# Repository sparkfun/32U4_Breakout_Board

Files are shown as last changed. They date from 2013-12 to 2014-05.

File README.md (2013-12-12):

ATMEGA32U4 Breakout Board
=========================

[ATMEGA32U4 Breakout 
*ATMEGA32U4 Breakout Board (DEV-11117)*](https://www.sparkfun.com/products/11117)

This breakout board is designed for folks who would like to program outside of the Arduino IDE. THe board
comes preloaded with the LUFA CDC bootloader, allowing code to be built in WinAVR and program the board over USB
using AVRDUDE. 

Repository Contents
-------------------
* **/Bootloaders** - CDC bootloader and instructions for installation
* **/Examples** - Example code for the board
* **/Hardware** - All Eagle design files (.brd, .sch)
* **/LUFA** - Instructions for setting up the LUFA bootloader

License Information
-------------------
The hardware is released under [Creative Commons Share-alike 3.0](http://creativecommons.org/licenses/by-sa/3.0/).  
All other code is open source so please feel free to do anything you want with it; you buy me a beer if you use this and we meet someday ([Beerware license](http://en.wikipedia.org/wiki/Beerware)).

Notes for Installation
----------------------
This directory contains the bootloader and example source files for
Sparkfun's 32u4 Breakout board. Both were built on WinXP sp3 with
WinAVR-20100110 and AVRDUDE 5.10.

The bootloader is a modified LUFA-130303 CDC bootloader.

The bootloader directory contains the source and hex file for the bootloader
that ships with this board.  When you first plug in the board to a Windows
machine, it will ask you for a driver.  Point it to the following directory:
\SFE_32U4_Breakout_Board\Bootloaders\CDC
It will find the driver file (LUFA CDC Bootloader.inf) there.

Once your machine recognizes the Virtual COM port, you're ready to take a
look at the examples and try uploading them to your board. See the readme in
the examples directory for more information.

Before you can build any projects, you'll need to download and install
WinAVR if you're using Windows. It can be found [here](http://sourceforge.net/projects/winavr/files/). 

Linux Users
-----------
You will need to install the following packages:
* **avr-gcc** - A port of the GNU C compiler to the AVR Architecture
* **avr-binutils** - Converts the object code into AVR-readable hex files
* **avr-libc** - AVR Library for stuff like accessing and manipulating registers
* **avrdude** - The software that actually drives the physical programming

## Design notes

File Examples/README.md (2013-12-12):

This directory contains various examples for the SparkFun 32u4 Breakout Board.
==============================================================================

All examples can be built using the command line.
Each example includes the appropriate source files and a hex file for quick testing.

To build:
----------
CD (change directory) into the appropriate folder such as:
\SFE_32U4_Breakout_Board\Examples\32U4_digital_output

Type the command 'make' or 'make all' and hit enter.
This builds the project and gives you a .hex file for the microcontroller.
Other build files are also created.

To clean:
---------
To get rid of all build files, use the command 'make clean'.

To program:
-----------
You can download a program a hex file to your Sparkfun 32u4 Breakout Board by first
hitting the physical reset button on the device.  This will put the device into
its bootloader state.  Then use the command 'make program'.

Examples:
---------
1. 32U4 digital output

Important files: main.c, makefile, main.hex

Demonstrates how to output a state, HIGH or LOW, to a pin.

2. 32U4 digital input

Important files: main.c, makefile, main.hex

Demonstrates to to read the input state of a pin, HIGH or LOW.

3. Sparkfun-VirtualSerial

Important files: VirtualSerial.c, makefile, VirtualSerial-ex1.hex, VirtualSerial-ex2.hex

Demonstrates basic functionality of how to send and receive characters from a PC via
USB and a virtual COM port.  Includes two examples.  VirtualSerial.c contains both
examples however, example 1 is active and 2 is commented out by default.  To try 
example 2, uncomment it and comment example 1.  The file has more detail.  If you
want to try either example without building the project, just download the
appropriate hex file to your board.

Notes concerning programming the board:
---------------------------------------

You will almost certainly have to change the line in the Makefile which specifies
which COM port to talk to. The line looks like this:
AVRDUDE_PORT = COM19
Change 'COM19' to 'COMx' where x is the number of the Sparkfun COM port that shows
up when you connect your 32u4 Breakout to the PC. This is an instruction for Windows,
however you do the same for MAC/Linux only they have fairly different COM port names.
Also, Windows asks for a driver the first time you plug in your board, direct it 
to the .inf file located in the \SFE_32U4_Breakout_Board\Bootloaders\CDC directory 
the first time you plug your board in.

Now that the board is programmed with an application the board will start in the 
user application when turned on.  If you want to reprogram a user application, 
you'll want to run the bootloader again.  To do this just hit the manual reset button
on the board.  Whenever the reset button is pressed, the bootloader runs.  So for 
programming in the future, just hit reset, type make program and hit enter.  
The programming will fail if the board isn't in its bootloader state.

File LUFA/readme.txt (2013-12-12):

                   _   _ _ ___ _
                  | | | | | __/ \
                  | |_| U | _| o | - The Lightweight USB
                  |___|___|_||_n_|    Framework for AVRs
                =========================================
                          Written by Dean Camera
                  dean [at] fourwalledcubicle [dot] com

                         http://www.lufa-lib.org
                =========================================

               LUFA is donation supported. To support LUFA,
             please donate at http://www.lufa-lib.org/donate

                For Commercial Licensing information, see
                     http://www.lufa-lib.org/license

Notes from SparkFun:

In order to compile the modified LUFA bootloader, or the Virtual Serial
example for your Sparkfun 32u4 Breakout Board, follow these instructions:

1. Download the LUFA Project, version 130303,  version 120219 for VirtualSerial

Visit http://www.lufa-lib.org, then download LUFA-130303.zip

Alternatively, use the following official link to the file:
lufa-lib.googlecode.com/files/LUFA-130303.zip

2. Extract the zip file somewhere on your computer.

3. Copy the contents of the 'LUFA' folder from the zip to this folder.

The folder should be in the main directory:
\LUFA-130303\LUFA

Copy everything in that folder to this one where this readme resides:
\SFE_32U4_Breakout_Board\LUFA

4. ???

5. Profit!

You can now compile the Sparkfun modified LUFA bootloader and the Virtual
Serial demo found in the following locations respectively:
\SFE_32U4_Breakout_Board\Bootloaders\CDC
\SFE_32U4_Breakout_Board\Examples\Sparkfun-VirtualSerial

Enjoy!!

Also, a note about other examples included with the LUFA download:

LUFA includes all sorts of other examples too but they need their makefiles 
to be customized to work for the 32u4 processor and their driver files 
(.inf files and Descriptors.c) to be customized for Sparkfun's 32u4 Breakout
Board. More specifically, you will have to change the VID and PID in those 
files for them to work with this specific board, so just a heads up.

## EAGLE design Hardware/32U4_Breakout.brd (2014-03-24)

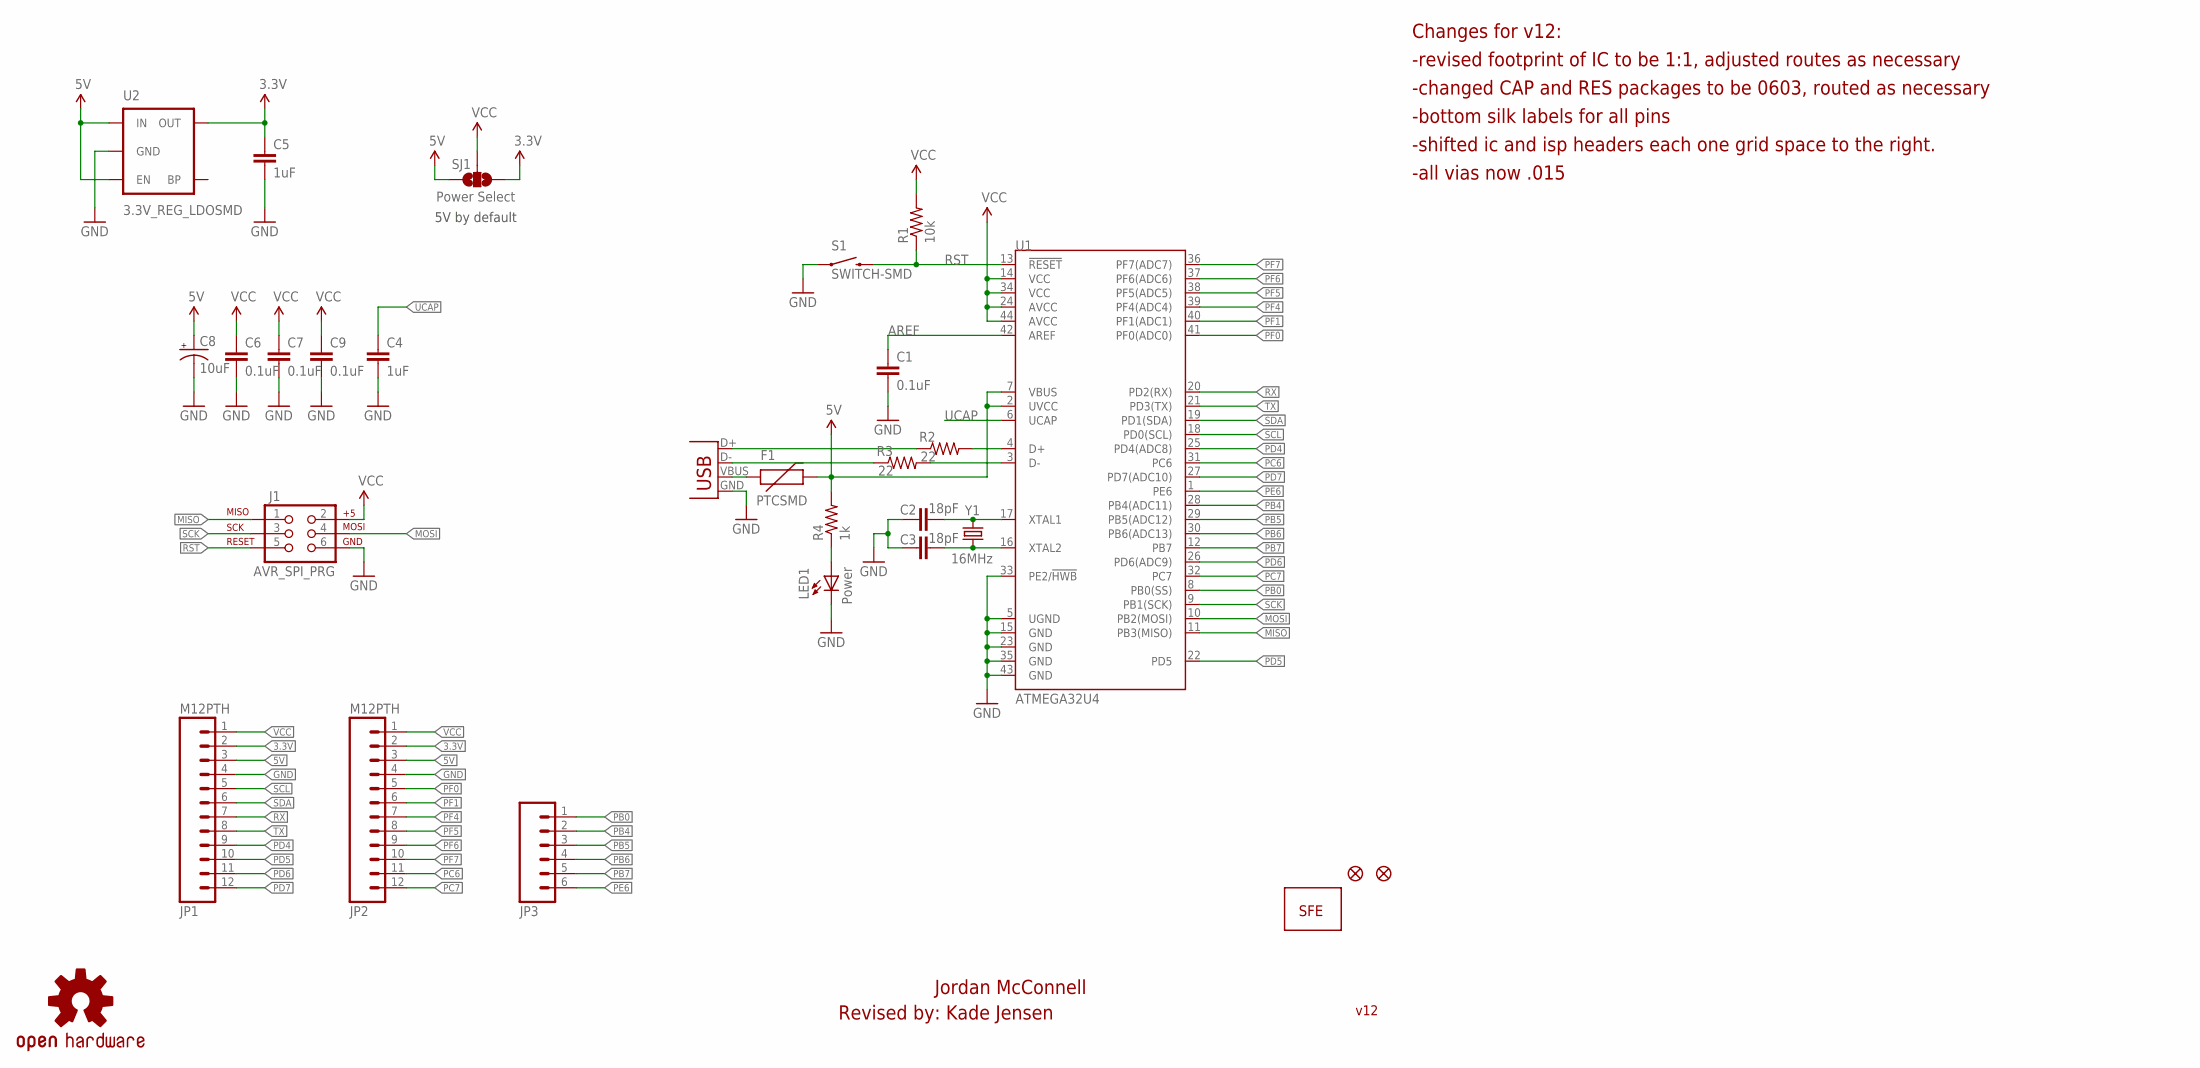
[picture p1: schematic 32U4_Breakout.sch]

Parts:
C1, C6, C7, C9: 0.1uF; 0603-CAP
C2, C3: 18pF; 0603-CAP
C4, C5: 1uF; 0603-CAP
C8: 10uF; EIA3216
F1: PTCSMD; PTC-1206
J1: AVR_SPI_PRG; 2X3
JP1, JP2: M12PTH; 1X12
JP3: M06SIP; 1X06
JP6, JP7: FIDUCIAL1X2; FIDUCIAL-1X2
JP8: LOGO-SFENEW; SFE-NEW-WEBLOGO
LED1: Power; LED-0603
R1: 10k; 0603-RES
R2, R3: 22; 0603-RES
R4: 1k; 0603-RES
S1: SWITCH-SMD; TACTILE_SWITCH_SMD
SJ1: Power Select; SJ_3_PASTE2&3
U1: ATMEGA32U4; QFN-44-NOPAD_1:1
U2: 3.3V_REG_LDOSMD; SOT23-5
U$6: OSHW-LOGOM; OSHW-LOGO-M
X1: USBSMD; USB-MINIB
Y1: 16MHz; CRYSTAL-SMD-5X3

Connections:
3.3V: C5.1, JP1.2, JP2.2, SJ1.1, U2.5 (OUT)
5V: C8.A (+), F1.2, JP1.3, JP2.3, R4.2, SJ1.3, U1.2 (UVCC), U1.7 (VBUS), U2.1 (IN), U2.3 (EN)
AREF: C1.1, U1.42 (AREF)
D+: R2.1, X1.D+
D-: R3.1, X1.D-
GND: C1.2, C2.1, C3.1, C4.2, C5.2, C6.2, C7.2, C8.C (-), C9.2, J1.6, JP1.4, JP2.4, LED1.C, S1.1, U1.5 (UGND), U1.15 (GND), U1.23 (GND), U1.33 (PE2/!HWB), U1.35 (GND), U1.43 (GND), U2.2 (GND), X1.GND
MISO: J1.1, U1.11 (PB3(MISO))
MOSI: J1.4, U1.10 (PB2(MOSI))
unnamed: C2.2, U1.17 (XTAL1), Y1.3 (2)
unnamed: C3.2, U1.16 (XTAL2), Y1.1
unnamed: F1.1, X1.VBUS
unnamed: R2.2, U1.4 (D+)
unnamed: R3.2, U1.3 (D-)
unnamed: LED1.A, R4.1
PB0: JP3.1, U1.8 (PB0(SS))
PB4: JP3.2, U1.28 (PB4(ADC11))
PB5: JP3.3, U1.29 (PB5(ADC12))
PB6: JP3.4, U1.30 (PB6(ADC13))
PB7: JP3.5, U1.12 (PB7)
PC6: JP2.11, U1.31 (PC6)
PC7: JP2.12, U1.32 (PC7)
PD4: JP1.9, U1.25 (PD4(ADC8))
PD5: JP1.10, U1.22 (PD5)
PD6: JP1.11, U1.26 (PD6(ADC9))
PD7: JP1.12, U1.27 (PD7(ADC10))
PE6: JP3.6, U1.1 (PE6)
PF0: JP2.5, U1.41 (PF0(ADC0))
PF1: JP2.6, U1.40 (PF1(ADC1))
PF4: JP2.7, U1.39 (PF4(ADC4))
PF5: JP2.8, U1.38 (PF5(ADC5))
PF6: JP2.9, U1.37 (PF6(ADC6))
PF7: JP2.10, U1.36 (PF7(ADC7))
RST: J1.5, R1.1, S1.3 (2), U1.13 (!RESET)
RX: JP1.7, U1.20 (PD2(RX))
SCK: J1.3, U1.9 (PB1(SCK))
SCL: JP1.5, U1.18 (PD0(SCL))
SDA: JP1.6, U1.19 (PD1(SDA))
TX: JP1.8, U1.21 (PD3(TX))
UCAP: C4.1, U1.6 (UCAP)
VCC: C6.1, C7.1, C9.1, J1.2, JP1.1, JP2.1, R1.2, SJ1.2, U1.14 (VCC), U1.24 (AVCC), U1.34 (VCC), U1.44 (AVCC)

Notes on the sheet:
Changes for v12:
-revised footprint of IC to be 1:1, adjusted routes as necessary
-changed CAP and RES packages to be 0603, routed as necessary
-bottom silk labels for all pins
-shifted ic and isp headers each one grid space to the right.
Jordan McConnell
Revised by: Kade Jensen
-all vias now .015
5V by default
v12

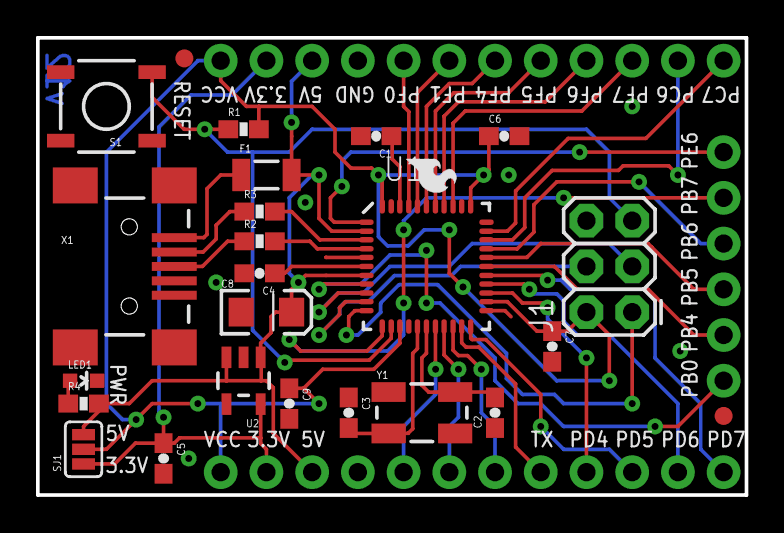
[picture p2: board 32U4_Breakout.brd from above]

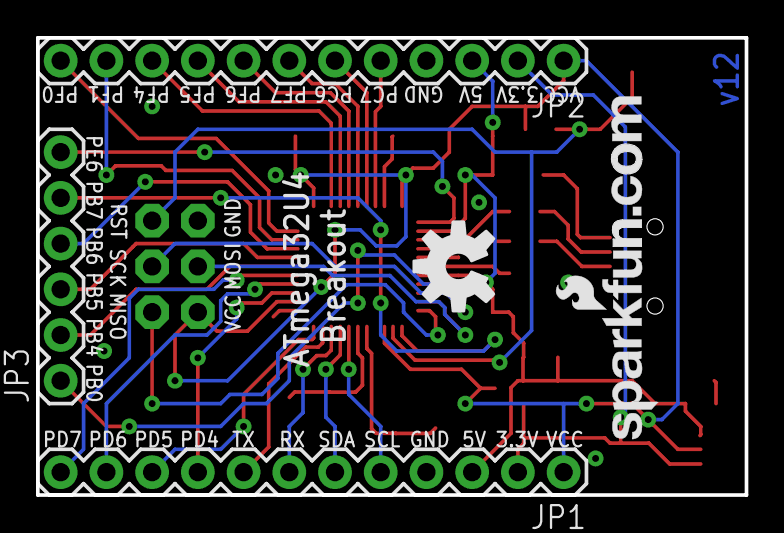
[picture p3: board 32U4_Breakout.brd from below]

Board: 2 copper layers, 39.4 x 25.4 mm, 30 parts (5 on the bottom side), 40 nets.

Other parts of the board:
JP5: LOGO-SFESK; SFE-LOGO-FLAME

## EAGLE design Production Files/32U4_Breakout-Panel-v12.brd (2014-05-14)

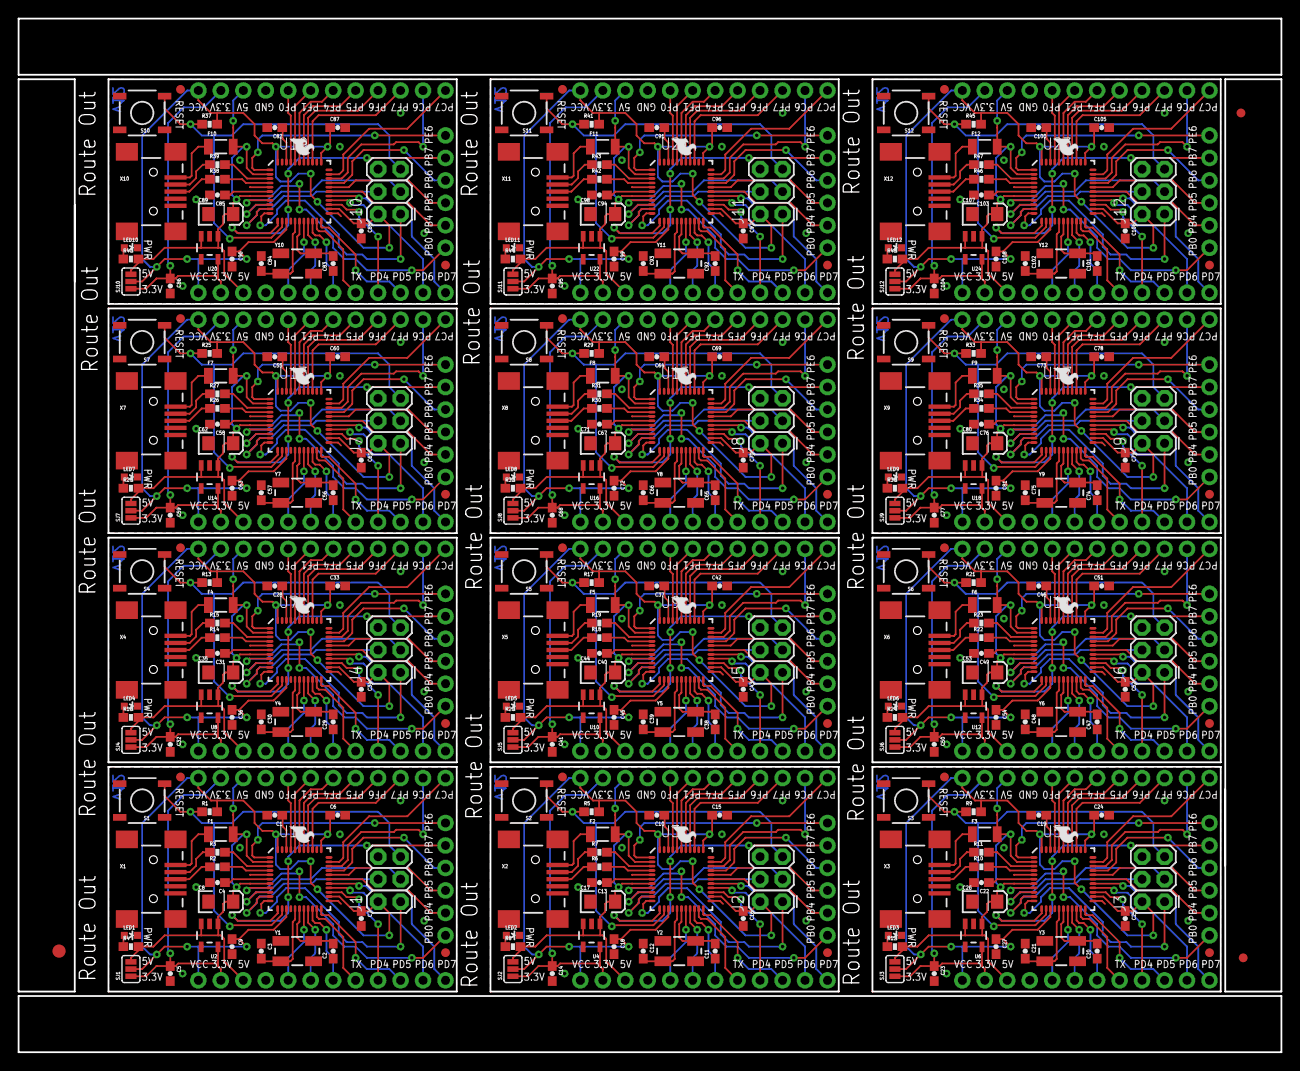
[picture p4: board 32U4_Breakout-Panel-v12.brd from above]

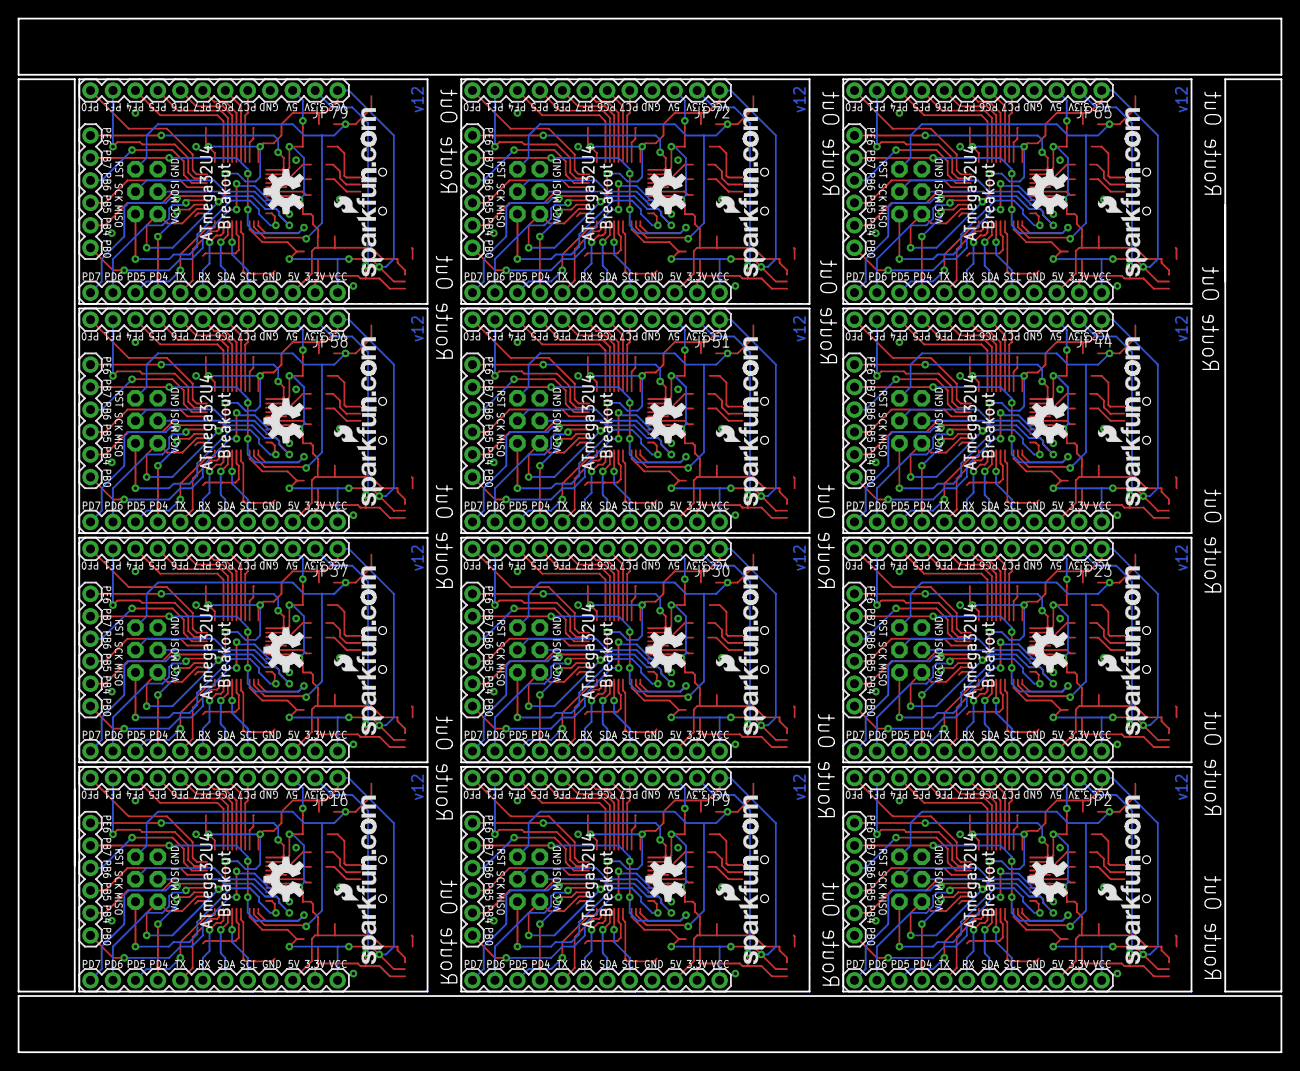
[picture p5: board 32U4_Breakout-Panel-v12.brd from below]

Board: 2 copper layers, 142.7 x 116.8 mm, 363 parts (60 on the bottom side), 480 nets.

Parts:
C1, C6, C7, C9, C10, C15, C16, C18, C19, C24, C25, C27, C28, C33, C34, C36, C37, C42, C43, C45, C46, C51, C52, C54, C55, C60, C61, C63, C64, C69, C70, C72, C73, C78, C79, C81, C82, C87, C88, C90, C91, C96, C97, C99, C100, C105, C106, C108: 0.1uF; 0603-CAP
C2, C3, C11, C12, C20, C21, C29, C30, C38, C39, C47, C48, C56, C57, C65, C66, C74, C75, C83, C84, C92, C93, C101, C102: 18pF; 0603-CAP
C4, C5, C13, C14, C22, C23, C31, C32, C40, C41, C49, C50, C58, C59, C67, C68, C76, C77, C85, C86, C94, C95, C103, C104: 1uF; 0603-CAP
C8, C17, C26, C35, C44, C53, C62, C71, C80, C89, C98, C107: 10uF; EIA3216
E$1: FIDUCIAL-1.5X3
E$4, E$5: FIDUCIAL-1X2
F1, F2, F3, F4, F5, F6, F7, F8, F9, F10, F11, F12: PTCSMD; PTC-1206
J1, J2, J3, J4, J5, J6, J7, J8, J9, J10, J11, J12: AVR_SPI_PRG; 2X3
JP1, JP2, JP4, JP9, JP15, JP16, JP22, JP23, JP29, JP30, JP36, JP37, JP43, JP44, JP50, JP51, JP57, JP58, JP64, JP65, JP71, JP72, JP78, JP79: M12PTH; 1X12
JP3, JP10, JP17, JP24, JP31, JP38, JP45, JP52, JP59, JP66, JP73, JP80: 1X06
JP5, JP11, JP18, JP25, JP32, JP39, JP46, JP53, JP60, JP67, JP74, JP81: LOGO-SFESK; SFE-LOGO-FLAME
JP6, JP7, JP12, JP13, JP19, JP20, JP26, JP27, JP33, JP34, JP40, JP41, JP47, JP48, JP54, JP55, JP61, JP62, JP68, JP69, JP75, JP76, JP82, JP83: FIDUCIAL1X2; FIDUCIAL-1X2
JP8, JP14, JP21, JP28, JP35, JP42, JP49, JP56, JP63, JP70, JP77, JP84: LOGO-SFENEW; SFE-NEW-WEBLOGO
LED1, LED2, LED3, LED4, LED5, LED6, LED7, LED8, LED9, LED10, LED11, LED12: Power; LED-0603
R1, R5, R9, R13, R17, R21, R25, R29, R33, R37, R41, R45: 10k; 0603-RES
R2, R3, R6, R7, R10, R11, R14, R15, R18, R19, R22, R23, R26, R27, R30, R31, R34, R35, R38, R39, R42, R43, R46, R47: 22; 0603-RES
R4, R8, R12, R16, R20, R24, R28, R32, R36, R40, R44, R48: 1k; 0603-RES
S1, S2, S3, S4, S5, S6, S7, S8, S9, S10, S11, S12: SWITCH-SMD; TACTILE_SWITCH_SMD
SJ1, SJ2, SJ3, SJ4, SJ5, SJ6, SJ7, SJ8, SJ9, SJ10, SJ11, SJ12: Power Select; SJ_3_PASTE2&3
U1, U3, U5, U7, U9, U11, U13, U15, U17, U19, U21, U23: ATMEGA32U4; QFN-44-NOPAD_1:1-LESS_PASTE
U2, U4, U6, U8, U10, U12, U14, U16, U18, U20, U22, U24: 3.3V_REG_LDOSMD; SOT23-5
U$1, U$2, U$3, U$4, U$5, U$6, U$7, U$8, U$9, U$10, U$11, U$12: OSHW-LOGOM; OSHW-LOGO-M
X1, X2, X3, X4, X5, X6, X7, X8, X9, X10, X11, X12: USBSMD; USB-MINIB
Y1, Y2, Y3, Y4, Y5, Y6, Y7, Y8, Y9, Y10, Y11, Y12: 16MHz; CRYSTAL-SMD-5X3

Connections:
3.3V: C5.1, JP1.2, JP2.2, SJ1.1, U2.5
3.3V1: C14.1, JP4.2, JP9.2, SJ2.1, U4.5
3.3V2: C23.1, JP15.2, JP16.2, SJ3.1, U6.5
3.3V3: C32.1, JP22.2, JP23.2, SJ4.1, U8.5
3.3V4: C41.1, JP29.2, JP30.2, SJ5.1, U10.5
3.3V5: C50.1, JP36.2, JP37.2, SJ6.1, U12.5
3.3V6: C59.1, JP43.2, JP44.2, SJ7.1, U14.5
3.3V7: C68.1, JP50.2, JP51.2, SJ8.1, U16.5
3.3V8: C77.1, JP57.2, JP58.2, SJ9.1, U18.5
3.3V9: C86.1, JP64.2, JP65.2, SJ10.1, U20.5
3.3V10: C95.1, JP71.2, JP72.2, SJ11.1, U22.5
3.3V11: C104.1, JP78.2, JP79.2, SJ12.1, U24.5
5V: C8.A, F1.2, JP1.3, JP2.3, R4.2, SJ1.3, U1.2, U1.7, U2.1, U2.3
5V1: C17.A, F2.2, JP4.3, JP9.3, R8.2, SJ2.3, U3.2, U3.7, U4.1, U4.3
5V2: C26.A, F3.2, JP15.3, JP16.3, R12.2, SJ3.3, U5.2, U5.7, U6.1, U6.3
5V3: C35.A, F4.2, JP22.3, JP23.3, R16.2, SJ4.3, U7.2, U7.7, U8.1, U8.3
5V4: C44.A, F5.2, JP29.3, JP30.3, R20.2, SJ5.3, U9.2, U9.7, U10.1, U10.3
5V5: C53.A, F6.2, JP36.3, JP37.3, R24.2, SJ6.3, U11.2, U11.7, U12.1, U12.3
5V6: C62.A, F7.2, JP43.3, JP44.3, R28.2, SJ7.3, U13.2, U13.7, U14.1, U14.3
5V7: C71.A, F8.2, JP50.3, JP51.3, R32.2, SJ8.3, U15.2, U15.7, U16.1, U16.3
5V8: C80.A, F9.2, JP57.3, JP58.3, R36.2, SJ9.3, U17.2, U17.7, U18.1, U18.3
5V9: C89.A, F10.2, JP64.3, JP65.3, R40.2, SJ10.3, U19.2, U19.7, U20.1, U20.3
5V10: C98.A, F11.2, JP71.3, JP72.3, R44.2, SJ11.3, U21.2, U21.7, U22.1, U22.3
5V11: C107.A, F12.2, JP78.3, JP79.3, R48.2, SJ12.3, U23.2, U23.7, U24.1, U24.3
AREF: C1.1, U1.42
AREF1: C10.1, U3.42
AREF2: C19.1, U5.42
AREF3: C28.1, U7.42
AREF4: C37.1, U9.42
AREF5: C46.1, U11.42
AREF6: C55.1, U13.42
AREF7: C64.1, U15.42
AREF8: C73.1, U17.42
AREF9: C82.1, U19.42
AREF10: C91.1, U21.42
AREF11: C100.1, U23.42
D+: R2.1, X1.D+
D+1: R6.1, X2.D+
D+2: R10.1, X3.D+
D+3: R14.1, X4.D+
D+4: R18.1, X5.D+
D+5: R22.1, X6.D+
D+6: R26.1, X7.D+
D+7: R30.1, X8.D+
D+8: R34.1, X9.D+
D+9: R38.1, X10.D+
D+10: R42.1, X11.D+
D+11: R46.1, X12.D+
D-: R3.1, X1.D-
D-1: R7.1, X2.D-
D-2: R11.1, X3.D-
D-3: R15.1, X4.D-
D-4: R19.1, X5.D-
D-5: R23.1, X6.D-
D-6: R27.1, X7.D-
D-7: R31.1, X8.D-
D-8: R35.1, X9.D-
D-9: R39.1, X10.D-
D-10: R43.1, X11.D-
D-11: R47.1, X12.D-
GND: C1.2, C2.1, C3.1, C4.2, C5.2, C6.2, C7.2, C8.C, C9.2, J1.6, JP1.4, JP2.4, LED1.C, S1.1, U1.5, U1.15, U1.23, U1.33, U1.35, U1.43, U2.2, X1.GND
GND1: C10.2, C11.1, C12.1, C13.2, C14.2, C15.2, C16.2, C17.C, C18.2, J2.6, JP4.4, JP9.4, LED2.C, S2.1, U3.5, U3.15, U3.23, U3.33, U3.35, U3.43, U4.2, X2.GND
GND2: C19.2, C20.1, C21.1, C22.2, C23.2, C24.2, C25.2, C26.C, C27.2, J3.6, JP15.4, JP16.4, LED3.C, S3.1, U5.5, U5.15, U5.23, U5.33, U5.35, U5.43, U6.2, X3.GND
GND3: C28.2, C29.1, C30.1, C31.2, C32.2, C33.2, C34.2, C35.C, C36.2, J4.6, JP22.4, JP23.4, LED4.C, S4.1, U7.5, U7.15, U7.23, U7.33, U7.35, U7.43, U8.2, X4.GND
GND4: C37.2, C38.1, C39.1, C40.2, C41.2, C42.2, C43.2, C44.C, C45.2, J5.6, JP29.4, JP30.4, LED5.C, S5.1, U9.5, U9.15, U9.23, U9.33, U9.35, U9.43, U10.2, X5.GND
GND5: C46.2, C47.1, C48.1, C49.2, C50.2, C51.2, C52.2, C53.C, C54.2, J6.6, JP36.4, JP37.4, LED6.C, S6.1, U11.5, U11.15, U11.23, U11.33, U11.35, U11.43, U12.2, X6.GND
GND6: C55.2, C56.1, C57.1, C58.2, C59.2, C60.2, C61.2, C62.C, C63.2, J7.6, JP43.4, JP44.4, LED7.C, S7.1, U13.5, U13.15, U13.23, U13.33, U13.35, U13.43, U14.2, X7.GND
GND7: C64.2, C65.1, C66.1, C67.2, C68.2, C69.2, C70.2, C71.C, C72.2, J8.6, JP50.4, JP51.4, LED8.C, S8.1, U15.5, U15.15, U15.23, U15.33, U15.35, U15.43, U16.2, X8.GND
GND8: C73.2, C74.1, C75.1, C76.2, C77.2, C78.2, C79.2, C80.C, C81.2, J9.6, JP57.4, JP58.4, LED9.C, S9.1, U17.5, U17.15, U17.23, U17.33, U17.35, U17.43, U18.2, X9.GND
GND9: C82.2, C83.1, C84.1, C85.2, C86.2, C87.2, C88.2, C89.C, C90.2, J10.6, JP64.4, JP65.4, LED10.C, S10.1, U19.5, U19.15, U19.23, U19.33, U19.35, U19.43, U20.2, X10.GND
GND10: C91.2, C92.1, C93.1, C94.2, C95.2, C96.2, C97.2, C98.C, C99.2, J11.6, JP71.4, JP72.4, LED11.C, S11.1, U21.5, U21.15, U21.23, U21.33, U21.35, U21.43, U22.2, X11.GND
GND11: C100.2, C101.1, C102.1, C103.2, C104.2, C105.2, C106.2, C107.C, C108.2, J12.6, JP78.4, JP79.4, LED12.C, S12.1, U23.5, U23.15, U23.23, U23.33, U23.35, U23.43, U24.2, X12.GND
MISO: J1.1, U1.11
MISO1: J2.1, U3.11
MISO2: J3.1, U5.11
MISO3: J4.1, U7.11
MISO4: J5.1, U9.11
MISO5: J6.1, U11.11
MISO6: J7.1, U13.11
MISO7: J8.1, U15.11
MISO8: J9.1, U17.11
MISO9: J10.1, U19.11
MISO10: J11.1, U21.11
MISO11: J12.1, U23.11
MOSI: J1.4, U1.10
MOSI1: J2.4, U3.10
MOSI2: J3.4, U5.10
MOSI3: J4.4, U7.10
MOSI4: J5.4, U9.10
MOSI5: J6.4, U11.10
MOSI6: J7.4, U13.10
MOSI7: J8.4, U15.10
MOSI8: J9.4, U17.10
MOSI9: J10.4, U19.10
MOSI10: J11.4, U21.10
MOSI11: J12.4, U23.10
unnamed: C11.2, U3.17, Y2.3
unnamed: C2.2, U1.17, Y1.3
unnamed: C3.2, U1.16, Y1.1
unnamed: F1.1, X1.VBUS
unnamed: C12.2, U3.16, Y2.1
unnamed: R2.2, U1.4
unnamed: R6.2, U3.4
unnamed: R3.2, U1.3
unnamed: LED1.A, R4.1
unnamed: R7.2, U3.3
unnamed: F2.1, X2.VBUS
unnamed: LED2.A, R8.1
unnamed: C20.2, U5.17, Y3.3
unnamed: C21.2, U5.16, Y3.1
unnamed: R10.2, U5.4
unnamed: R11.2, U5.3
unnamed: F3.1, X3.VBUS
unnamed: LED3.A, R12.1
unnamed: C29.2, U7.17, Y4.3
unnamed: C30.2, U7.16, Y4.1
unnamed: R14.2, U7.4
unnamed: R15.2, U7.3
unnamed: F4.1, X4.VBUS
unnamed: LED4.A, R16.1
unnamed: C38.2, U9.17, Y5.3
unnamed: C39.2, U9.16, Y5.1
unnamed: R18.2, U9.4
unnamed: R19.2, U9.3
unnamed: F5.1, X5.VBUS
unnamed: LED5.A, R20.1
unnamed: C47.2, U11.17, Y6.3
unnamed: C48.2, U11.16, Y6.1
unnamed: R22.2, U11.4
unnamed: R23.2, U11.3
unnamed: F6.1, X6.VBUS
unnamed: LED6.A, R24.1
unnamed: C56.2, U13.17, Y7.3
unnamed: C57.2, U13.16, Y7.1
unnamed: R26.2, U13.4
unnamed: R27.2, U13.3
unnamed: F7.1, X7.VBUS
unnamed: LED7.A, R28.1
unnamed: C65.2, U15.17, Y8.3
unnamed: C66.2, U15.16, Y8.1
unnamed: R30.2, U15.4
unnamed: R31.2, U15.3
unnamed: F8.1, X8.VBUS
unnamed: LED8.A, R32.1
unnamed: C74.2, U17.17, Y9.3
unnamed: C75.2, U17.16, Y9.1
unnamed: R34.2, U17.4
unnamed: R35.2, U17.3
unnamed: F9.1, X9.VBUS
unnamed: LED9.A, R36.1
unnamed: C83.2, U19.17, Y10.3
unnamed: C84.2, U19.16, Y10.1
unnamed: R38.2, U19.4
unnamed: R39.2, U19.3
unnamed: F10.1, X10.VBUS
unnamed: LED10.A, R40.1
unnamed: C92.2, U21.17, Y11.3
unnamed: C93.2, U21.16, Y11.1
unnamed: R42.2, U21.4
unnamed: R43.2, U21.3
unnamed: F11.1, X11.VBUS
unnamed: LED11.A, R44.1
unnamed: C101.2, U23.17, Y12.3
unnamed: C102.2, U23.16, Y12.1
unnamed: R46.2, U23.4
unnamed: R47.2, U23.3
unnamed: F12.1, X12.VBUS
unnamed: LED12.A, R48.1
PB0: JP3.1, U1.8
PB1: JP10.2, U3.28
PB2: JP10.3, U3.29
PB3: JP10.4, U3.30
PB4: JP3.2, U1.28
PB5: JP3.3, U1.29
PB6: JP3.4, U1.30
PB7: JP3.5, U1.12
PB8: JP10.5, U3.12
PB9: JP10.1, U3.8
PB10: JP17.2, U5.28
PB11: JP17.3, U5.29
PB12: JP17.4, U5.30
PB13: JP17.5, U5.12
PB14: JP17.1, U5.8
PB15: JP24.2, U7.28
PB16: JP24.3, U7.29
PB17: JP24.4, U7.30
PB18: JP24.5, U7.12
PB19: JP24.1, U7.8
PB20: JP31.2, U9.28
PB21: JP31.3, U9.29
PB22: JP31.4, U9.30
PB23: JP31.5, U9.12
PB24: JP31.1, U9.8
PB25: JP38.2, U11.28
PB26: JP38.3, U11.29
PB27: JP38.4, U11.30
PB28: JP38.5, U11.12
PB29: JP38.1, U11.8
PB30: JP45.2, U13.28
PB31: JP45.3, U13.29
PB32: JP45.4, U13.30
PB33: JP45.5, U13.12
PB34: JP45.1, U13.8
PB35: JP52.2, U15.28
PB36: JP52.3, U15.29
PB37: JP52.4, U15.30
PB38: JP52.5, U15.12
PB39: JP52.1, U15.8
PB40: JP59.2, U17.28
PB41: JP59.3, U17.29
PB42: JP59.4, U17.30
PB43: JP59.5, U17.12
PB44: JP59.1, U17.8
PB45: JP66.2, U19.28
PB46: JP66.3, U19.29
PB47: JP66.4, U19.30
PB48: JP66.5, U19.12
PB49: JP66.1, U19.8
PB50: JP73.2, U21.28
PB51: JP73.3, U21.29
PB52: JP73.4, U21.30
PB53: JP73.5, U21.12
PB54: JP73.1, U21.8
PB55: JP80.2, U23.28
PB56: JP80.3, U23.29
PB57: JP80.4, U23.30
PB58: JP80.5, U23.12
PB59: JP80.1, U23.8
PC1: JP9.11, U3.31
PC2: JP9.12, U3.32
PC3: JP16.11, U5.31
PC4: JP16.12, U5.32
PC5: JP23.11, U7.31
PC6: JP2.11, U1.31
PC7: JP2.12, U1.32
PC8: JP23.12, U7.32
PC9: JP30.11, U9.31
PC10: JP30.12, U9.32
PC11: JP37.11, U11.31
PC12: JP37.12, U11.32
PC13: JP44.11, U13.31
PC14: JP44.12, U13.32
PC15: JP51.11, U15.31
PC16: JP51.12, U15.32
PC17: JP58.11, U17.31
PC18: JP58.12, U17.32
PC19: JP65.11, U19.31
PC20: JP65.12, U19.32
PC21: JP72.11, U21.31
PC22: JP72.12, U21.32
PC23: JP79.11, U23.31
PC24: JP79.12, U23.32
PD1: JP4.9, U3.25
PD2: JP4.12, U3.27
PD3: JP4.11, U3.26
PD4: JP1.9, U1.25
PD5: JP1.10, U1.22
PD6: JP1.11, U1.26
PD7: JP1.12, U1.27
PD8: JP4.10, U3.22
PD9: JP15.9, U5.25
PD10: JP15.12, U5.27
PD11: JP15.11, U5.26
PD12: JP15.10, U5.22
PD13: JP22.9, U7.25
PD14: JP22.12, U7.27
PD15: JP22.11, U7.26
PD16: JP22.10, U7.22
PD17: JP29.9, U9.25
PD18: JP29.12, U9.27
PD19: JP29.11, U9.26
PD20: JP29.10, U9.22
PD21: JP36.9, U11.25
PD22: JP36.12, U11.27
PD23: JP36.11, U11.26
PD24: JP36.10, U11.22
PD25: JP43.9, U13.25
PD26: JP43.12, U13.27
PD27: JP43.11, U13.26
PD28: JP43.10, U13.22
PD29: JP50.9, U15.25
PD30: JP50.12, U15.27
PD31: JP50.11, U15.26
PD32: JP50.10, U15.22
PD33: JP57.9, U17.25
PD34: JP57.12, U17.27
PD35: JP57.11, U17.26
PD36: JP57.10, U17.22
PD37: JP64.9, U19.25
PD38: JP64.12, U19.27
PD39: JP64.11, U19.26
PD40: JP64.10, U19.22
PD41: JP71.9, U21.25
PD42: JP71.12, U21.27
PD43: JP71.11, U21.26
PD44: JP71.10, U21.22
PD45: JP78.9, U23.25
PD46: JP78.12, U23.27
PD47: JP78.11, U23.26
PD48: JP78.10, U23.22
PE1: JP10.6, U3.1
PE2: JP17.6, U5.1
PE3: JP24.6, U7.1
PE4: JP31.6, U9.1
PE5: JP38.6, U11.1
PE6: JP3.6, U1.1
PE7: JP45.6, U13.1
PE8: JP52.6, U15.1
PE9: JP59.6, U17.1
PE10: JP66.6, U19.1
PE11: JP73.6, U21.1
PE12: JP80.6, U23.1
PF0: JP2.5, U1.41
PF1: JP2.6, U1.40
PF2: JP9.10, U3.36
PF3: JP9.9, U3.37
PF4: JP2.7, U1.39
PF5: JP2.8, U1.38
PF6: JP2.9, U1.37
PF7: JP2.10, U1.36
PF8: JP9.8, U3.38
PF9: JP9.7, U3.39
PF10: JP9.6, U3.40
PF11: JP9.5, U3.41
PF12: JP16.10, U5.36
PF13: JP16.9, U5.37
PF14: JP16.8, U5.38
PF15: JP16.7, U5.39
PF16: JP16.6, U5.40
PF17: JP16.5, U5.41
PF18: JP23.10, U7.36
PF19: JP23.9, U7.37
PF20: JP23.8, U7.38
PF21: JP23.7, U7.39
PF22: JP23.6, U7.40
PF23: JP23.5, U7.41
PF24: JP30.10, U9.36
PF25: JP30.9, U9.37
PF26: JP30.8, U9.38
PF27: JP30.7, U9.39
PF28: JP30.6, U9.40
PF29: JP30.5, U9.41
PF30: JP37.10, U11.36
PF31: JP37.9, U11.37
PF32: JP37.8, U11.38
PF33: JP37.7, U11.39
PF34: JP37.6, U11.40
PF35: JP37.5, U11.41
PF36: JP44.10, U13.36
PF37: JP44.9, U13.37
PF38: JP44.8, U13.38
PF39: JP44.7, U13.39
PF40: JP44.6, U13.40
PF41: JP44.5, U13.41
PF42: JP51.10, U15.36
PF43: JP51.9, U15.37
PF44: JP51.8, U15.38
PF45: JP51.7, U15.39
PF46: JP51.6, U15.40
PF47: JP51.5, U15.41
PF48: JP58.10, U17.36
PF49: JP58.9, U17.37
PF50: JP58.8, U17.38
PF51: JP58.7, U17.39
PF52: JP58.6, U17.40
PF53: JP58.5, U17.41
PF54: JP65.10, U19.36
PF55: JP65.9, U19.37
PF56: JP65.8, U19.38
PF57: JP65.7, U19.39
PF58: JP65.6, U19.40
PF59: JP65.5, U19.41
PF60: JP72.10, U21.36
PF61: JP72.9, U21.37
PF62: JP72.8, U21.38
PF63: JP72.7, U21.39
PF64: JP72.6, U21.40
PF65: JP72.5, U21.41
PF66: JP79.10, U23.36
PF67: JP79.9, U23.37
PF68: JP79.8, U23.38
PF69: JP79.7, U23.39
PF70: JP79.6, U23.40
PF71: JP79.5, U23.41
RST: J1.5, R1.1, S1.3, U1.13
RST1: J2.5, R5.1, S2.3, U3.13
RST2: J3.5, R9.1, S3.3, U5.13
RST3: J4.5, R13.1, S4.3, U7.13
RST4: J5.5, R17.1, S5.3, U9.13
RST5: J6.5, R21.1, S6.3, U11.13
RST6: J7.5, R25.1, S7.3, U13.13
RST7: J8.5, R29.1, S8.3, U15.13
RST8: J9.5, R33.1, S9.3, U17.13
RST9: J10.5, R37.1, S10.3, U19.13
RST10: J11.5, R41.1, S11.3, U21.13
RST11: J12.5, R45.1, S12.3, U23.13
RX: JP1.7, U1.20
RX1: JP4.7, U3.20
RX2: JP15.7, U5.20
RX3: JP22.7, U7.20
RX4: JP29.7, U9.20
RX5: JP36.7, U11.20
RX6: JP43.7, U13.20
RX7: JP50.7, U15.20
RX8: JP57.7, U17.20
RX9: JP64.7, U19.20
RX10: JP71.7, U21.20
RX11: JP78.7, U23.20
SCK: J1.3, U1.9
SCK1: J2.3, U3.9
SCK2: J3.3, U5.9
SCK3: J4.3, U7.9
SCK4: J5.3, U9.9
SCK5: J6.3, U11.9
SCK6: J7.3, U13.9
SCK7: J8.3, U15.9
SCK8: J9.3, U17.9
SCK9: J10.3, U19.9
SCK10: J11.3, U21.9
SCK11: J12.3, U23.9
SCL: JP1.5, U1.18
SCL1: JP4.5, U3.18
SCL2: JP15.5, U5.18
SCL3: JP22.5, U7.18
SCL4: JP29.5, U9.18
SCL5: JP36.5, U11.18
SCL6: JP43.5, U13.18
SCL7: JP50.5, U15.18
SCL8: JP57.5, U17.18
SCL9: JP64.5, U19.18
SCL10: JP71.5, U21.18
SCL11: JP78.5, U23.18
SDA: JP1.6, U1.19
SDA1: JP4.6, U3.19
SDA2: JP15.6, U5.19
SDA3: JP22.6, U7.19
SDA4: JP29.6, U9.19
SDA5: JP36.6, U11.19
SDA6: JP43.6, U13.19
SDA7: JP50.6, U15.19
SDA8: JP57.6, U17.19
SDA9: JP64.6, U19.19
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

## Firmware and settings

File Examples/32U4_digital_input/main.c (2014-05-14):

/* Created 05/22/2012 by Jordan McConnell at Sparkfun Electronics
 * This code is beerware, you know what I'm sayin'?
 *
 * Built on WinXP SP3 and WinAVR-20100110, AVRDUDE 5.10
 *
 * This code is a simple example of digital input for Sparkfun's
 * 32U4 Breakout Board using C and standard AVR libraries.  It
 * teaches you how to read the status of a digital pin to determine
 * whether its current status is HIGH or LOW.
 *
 * Pin PF0 is used as a digital input.  If its status is HIGH,
 * pin PD5 toggles each second, if it's status is LOW, pin PD6
 * toggles each second instead.
 *
 * The user can connect LED's to pins PD5 and PD6 or use a multimeter
 * to verify operation.  If pin PF0 is left unconnected, it's status
 * will be HIGH due to internal pullup resistors, and PD5 toggles.
 * If PF0 is connected to ground, PD6 toggles each second instead.
 */

// Libraries for register names and the delay function
#include <avr/io.h>
#include <util/delay.h>

// Macros to make bit manipulation easier
#define set_bit(address,bit) (address |= (1<<bit))
#define clear_bit(address,bit) (address &= ~(1<<bit))
#define toggle_bit(address,bit) (address ^= (1<<bit))

// This macro is for checking if a certain bit is set in a given register.
// This is useful here for checking the status of individual input pins.
#define check_bit(address,bit) ((address & (1<<bit)) == (1<<bit))

int main(void)
{
    // The following line sets bit 5 HIGH in register DDRD
    set_bit(DDRD,5); // Pin PD5 is now configured as an OUTPUT
    set_bit(DDRD,6); // Pin PD6 is now configured as an OUTPUT

    // The following line sets bit 0 LOW in register DDRF
    clear_bit(DDRF,0); // Pin PF0 is now configured as an INPUT
    set_bit(PORTF,0); // Turn on internal pullups for PF0

    while(1)
    {
        // PINF is the register you have to read to check if a particular
        // pin on port F (PFx) is HIGH or LOW
        if(check_bit(PINF,0))
        {
            // If PF0 is HIGH, toggle pin PD5's output status
            toggle_bit(PORTD,5);
        }
        else
        {
            // If PF0 is LOW, toggle pin PD6's output status
            toggle_bit(PORTD,6);
        }

        _delay_ms(1000); // Delay 1 second before checking PF0 again

    }

    return 0;
}

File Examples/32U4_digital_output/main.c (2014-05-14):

/* Created 05/20/2012 by Jordan McConnell at Sparkfun Electronics
 * This code is beerware, you know what I'm sayin'?
 *
 * Built on WinXP SP3 and WinAVR-20100110, AVRDUDE 5.10
 *
 * This code is a simple example of digital output for Sparkfun's
 * 32U4 Breakout Board using C and standard AVR libraries.  It
 * teaches you how to set a pin high or low or toggle it from one
 * state to the other using pin PD5 as an example.
 *
 * The user can use a multimeter or LED on pin PD5 to verify that
 * the pin is indeed changing state between HIGH and LOW each second.
 */

// Libraries for register names (DDRD, PORTD) and the delay function
#include <avr/io.h>
#include <util/delay.h>

// Macros to make bit manipulation easier
// Macro tutorial found here: http://www.cprogramming.com/tutorial/cpreprocessor.html
// Bit manipulation tutorial found here: http://www.avrfreaks.net/index.php?name=PNphpBB2&file=viewtopic&t=37871
#define set_bit(address,bit) (address |= (1<<bit)) // sets BIT to 1 in the register specified with ADDRESS
#define clear_bit(address,bit) (address &= ~(1<<bit)) // sets BIT to 0 in the register specified with ADDRESS
#define toggle_bit(address,bit) (address ^= (1<<bit)) // sets BIT to the opposite of what it's set to currently in the register specified with ADDRESS

int main(void)
{
    // The following line sets bit 5 high in register DDRD
    set_bit(DDRD,5); // Pin PD5 is now configured as an OUTPUT
    set_bit(PORTD,5); // Pin PD5 is now HIGH

    _delay_ms(1000);  // Delay for 1 second

    // The following line sets bit 5 low in register PORTD
    clear_bit(PORTD,5); // Pin PD5 is now LOW

    while(1)
    {
        _delay_ms(1000);
        toggle_bit(PORTD,5); // PD5 switches from LOW to HIGH or vice versa
    }

    return 0;
}

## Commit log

2013-09-23 Added Hardware folder with Eagle files
    Added board and schematic files for v11.
    [32U4_Breakout.brd, 32U4_Breakout.sch]
2013-09-23 Updated to v12 eagle files
    Eagle files for QC board revision and schematic updates.
    [32U4_Breakout.brd, 32U4_Breakout.sch]
2013-10-23 Moved C5 and a couple tarces
    Moved C5 and a couple traces to prevent problems with top silk on the
    vcc jumper.
    [32U4_Breakout.brd]
2013-10-25 Panel Created
    normal sized panel for now.
    [32U4_Breakout-Panel-v12.brd]
2014-05-14 changed paste layer on IC
    [32U4_Breakout-Panel-v12.brd]

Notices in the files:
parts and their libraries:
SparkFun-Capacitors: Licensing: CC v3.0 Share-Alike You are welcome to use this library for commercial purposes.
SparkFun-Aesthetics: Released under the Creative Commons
